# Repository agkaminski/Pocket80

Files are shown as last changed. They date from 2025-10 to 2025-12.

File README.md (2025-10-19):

# Pocket80

Personal computer with monitor software that fits into a pocket. Successor to the
[Pocket265](https://github.com/agkaminski/Pocket265) with more features and more
powerful Z80 CPU onboard.

Key features:
- Z80 CPU @3.6864 MHz,
- 32 KB of SRAM,
- 32 KB of EEPROM,
- Z80 CTC:
    - interval system timer,
    - baudrate generator,
    - sound (via onboard piezo driver).
- Z80 SIO:
    - USB UART port,
    - expansion connector UART port,
    - baudrate of up to 14400 baud/s.
- Z80 PIO:
    - onboard 64 KB of I2C EERPOM memory,
    - heartbeat LED,
    - expansion connector GPIOs.
- Build-in LiPo battery:
    - USB-C battery charging circuitry,
    - battery level indicator.

## Memory map

| Start  | End | Description |
|---|---|---|
| 0x0000 | 0x7FFF | ROM |
| 0x8000 | 0xFFFF | RAM |

## IO Map

| Start | End  | Description |
|---|---|---|
| 0x00  | 0x1F | Z80 CTC |
| 0x20  | 0x3F | Z80 SIO |
| 0x40  | 0x5F | Z80 PIO |
| 0x60  | 0x7F | Sound reset |
| 0x80  | 0x9F | Keyboard |
| 0xA0  | 0xBF | Display 1 (leftmost) |
| 0xC0  | 0xDF | Display 2 |
| 0xE0  | 0xFF | Display 3 |

## PCB visualisation

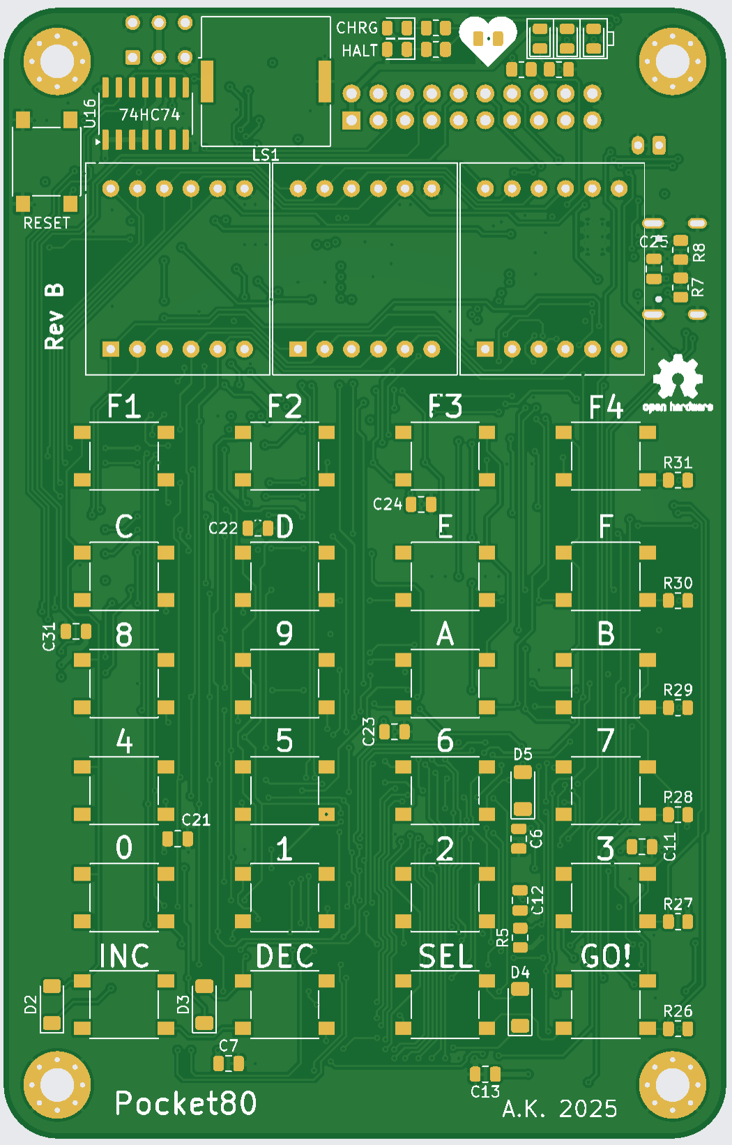
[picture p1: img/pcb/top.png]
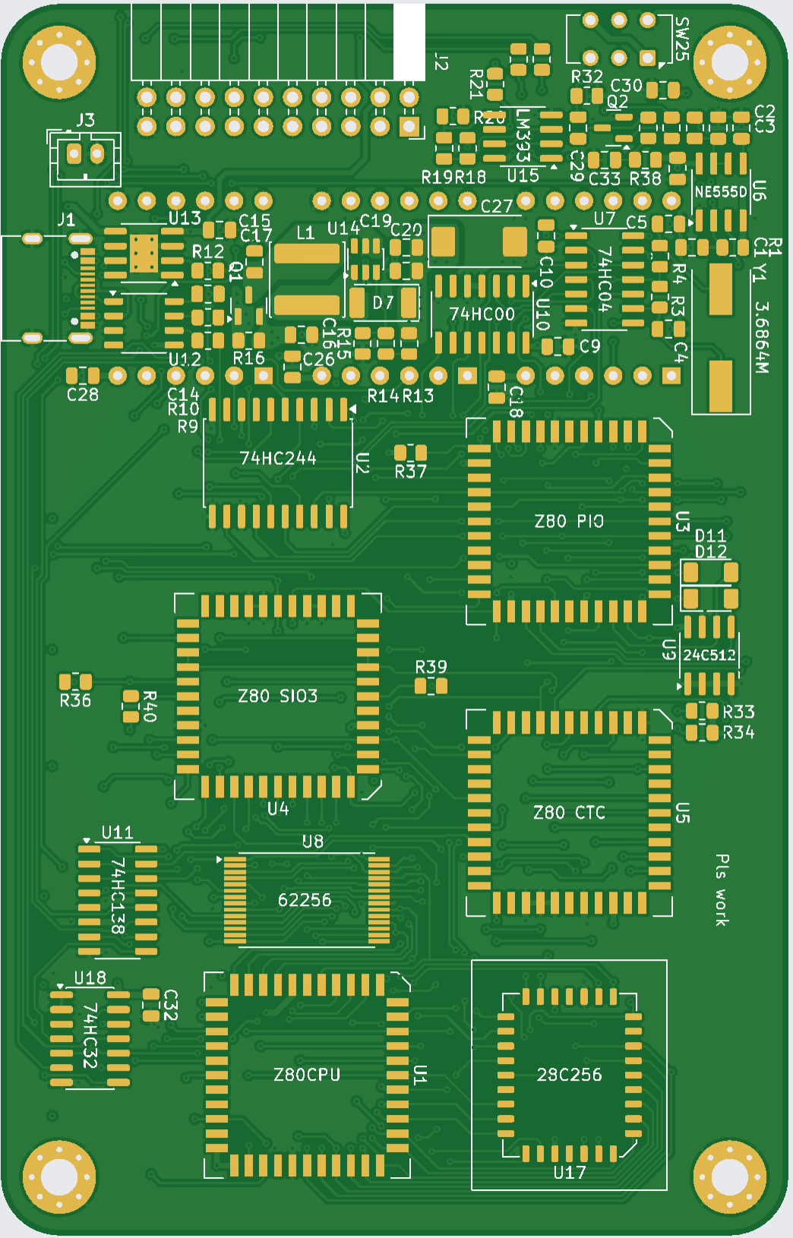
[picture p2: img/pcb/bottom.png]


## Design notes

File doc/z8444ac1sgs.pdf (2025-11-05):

Powered by ICminer.com Electronic-Library Service CopyRight 2003

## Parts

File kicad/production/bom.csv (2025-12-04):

Designator | Footprint | Quantity | Value | LCSC Part #
C1, C10, C11, C12, C13, C14, C17, C18, C19, C21, C22, C23, C24, C25, C26, C28, C30, C31, C32, C6, C7, C8, C9 | 0805 | 23 | 100n
C15, C16, C20 | 0805 | 3 | 22u
C2 | 0805 | 1 | 10n
C27 | CP_EIA-7343-15_Kemet-W | 1 | 68u
C29 | 0805 | 1 | 1u
C3 | 0805 | 1 | 220n
C33 | 0805 | 1 | 2u2
C4, C5 | 0805 | 2 | 22p
D1 | 0805 | 1 | HALT
D10 | 0805 | 1 | MEDIUM
D11, D12, D2, D3, D4, D5 | D_MiniMELF | 6 | 1N4148
D13 | 0805 | 1 | HEARTBEAT
D6 | 0805 | 1 | CHRG
D7 | 2010 | 1 | SS34
D8 | 0805 | 1 | POWER
D9 | 0805 | 1 | HIGH
DL1, DL2, DL3 | DL1414 | 3 | ~
J1 | USB_C_Receptacle_G-Switch_GT-USB-7010ASV | 1 | USB_C_Receptacle_USB2.0_14P
J2 | PinSocket_2x10_P2.54mm_Horizontal | 1 | Conn_02x10_Odd_Even
J3 | JST_PH_B2B-PH-K_1x02_P2.00mm_Vertical | 1 | Conn_01x02
L1 | L_Sunlord_SWPA6040S | 1 | 220u
LS1 | Buzzer_Murata_PKLCS1212E | 1 | Speaker_Crystal
Q1 | SOT-23 | 1 | IRLML6402
Q2 | SOT-23 | 1 | BC847
R1, R25, R26, R27, R28, R29, R30, R31, R32, R36, R37, R39, R40, R5 | 0805 | 14 | 10K
R10, R9 | 0805 | 2 | 220R
R11, R15, R17, R24, R4, R6 | 0805 | 6 | 1K
R12 | 0805 | 1 | 2K7
R13, R22, R35 | 0805 | 3 | 470R
R14 | 0805 | 1 | 6K8
R16, R2, R3 | 0805 | 3 | 1M
R18 | 0805 | 1 | 68K
R19 | 0805 | 1 | 47K
R20 | 0805 | 1 | 220K
R21 | 0805 | 1 | 100K
R23 | 0805 | 1 | 680R
R33, R34 | 0805 | 2 | 4K7
R38 | 0805 | 1 | 510R
R7, R8 | 0805 | 2 | 5K1
SW1 | SW_SPST_PTS645 | 1 | F1
SW10 | SW_SPST_PTS645 | 1 | 4
SW11 | SW_SPST_PTS645 | 1 | 9
SW12 | SW_SPST_PTS645 | 1 | 5
SW13 | SW_SPST_PTS645 | 1 | A
SW14 | SW_SPST_PTS645 | 1 | 6
SW15 | SW_SPST_PTS645 | 1 | B
SW16 | SW_SPST_PTS645 | 1 | 7
SW17 | SW_SPST_PTS645 | 1 | 0
SW18 | SW_SPST_PTS645 | 1 | INC
SW19 | SW_SPST_PTS645 | 1 | 1
SW2 | SW_SPST_PTS645 | 1 | F2
SW20 | SW_SPST_PTS645 | 1 | DEC
SW21 | SW_SPST_PTS645 | 1 | 2
SW22 | SW_SPST_PTS645 | 1 | SEL
SW23 | SW_SPST_PTS645 | 1 | 3
SW24 | SW_SPST_PTS645 | 1 | GO!
SW25 | SW_CK_JS202011AQN_DPDT_Angled | 1 | SW_Push_DPDT
SW26 | SW_SPST_PTS645 | 1 | RESET
SW3 | SW_SPST_PTS645 | 1 | F3
SW4 | SW_SPST_PTS645 | 1 | F4
SW5 | SW_SPST_PTS645 | 1 | C
SW6 | SW_SPST_PTS645 | 1 | D
SW7 | SW_SPST_PTS645 | 1 | E
SW8 | SW_SPST_PTS645 | 1 | F
SW9 | SW_SPST_PTS645 | 1 | 8
U1 | PLCC-44 | 1 | Z80CPU
U10 | SO-14_3.9x8.65mm_P1.27mm | 1 | 74HC00
U11 | SOIC-16_3.9x9.9mm_P1.27mm | 1 | 74HC138
U12 | SOP-8_3.9x4.9mm_P1.27mm | 1 | CH340N
U13 | SOIC-8-1EP_3.9x4.9mm_P1.27mm_EP2.41x3.3mm_ThermalVias | 1 | TP4056-42-ESOP8
U14 | TSOT-23-6 | 1 | SX1308
U15 | SOIC-8_3.9x4.9mm_P1.27mm | 1 | LM393
U16 | SO-14_3.9x8.65mm_P1.27mm | 1 | 74HC74
U17 | PLCC-32_11.4x14.0mm_P1.27mm | 1 | 28C256
U18 | SO-14_3.9x8.65mm_P1.27mm | 1 | 74HC32
U2 | SOIC-20W_7.5x12.8mm_P1.27mm | 1 | 74HC244
U3 | PLCC-44 | 1 | Z80 PIO
U4 | PLCC-44 | 1 | Z80 SIO3
U5 | PLCC-44 | 1 | Z80 CTC
U6 | SOIC-8_3.9x4.9mm_P1.27mm | 1 | NE555D
U7 | SO-14_3.9x8.65mm_P1.27mm | 1 | 74HC04
U8 | TSOP-I-28_11.8x8mm_P0.55mm | 1 | 62256
U9 | SOIC-8_3.9x4.9mm_P1.27mm | 1 | 24C512
Y1 | Crystal_SMD_HC49-SD | 1 | 3.6864M

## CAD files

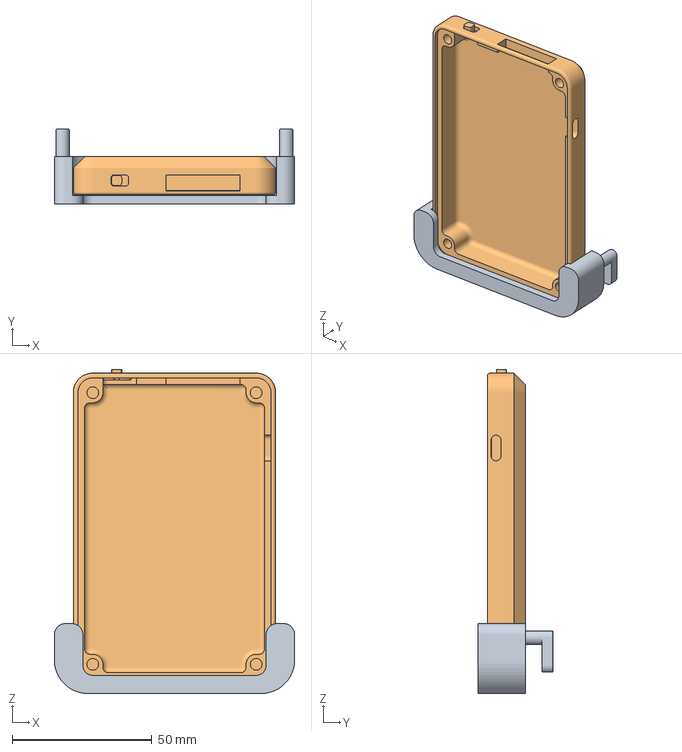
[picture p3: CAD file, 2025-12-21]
3d/skadis_hanger.FCStd
86.0 x 27.0 x 115.9 mm
hanger
caseB

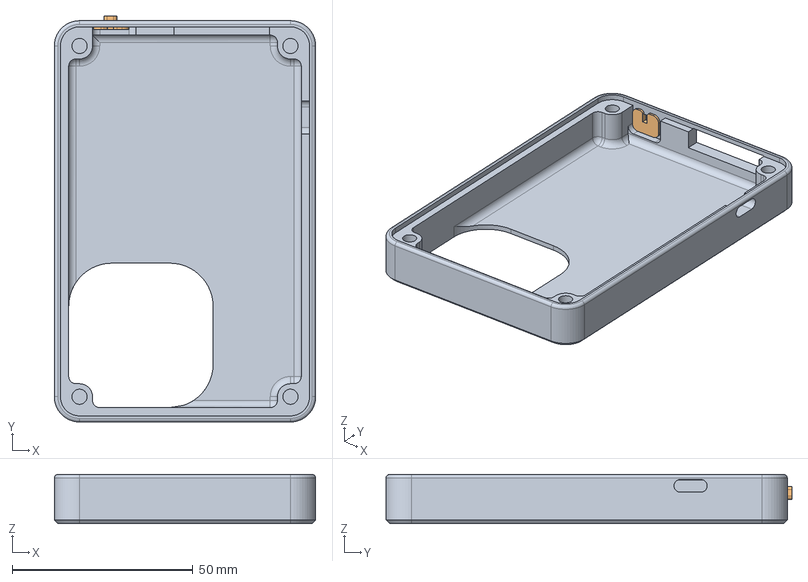
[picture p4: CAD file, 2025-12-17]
3d/caseB_dev.FCStd
72.4 x 112.5 x 13.6 mm
Case
Switch

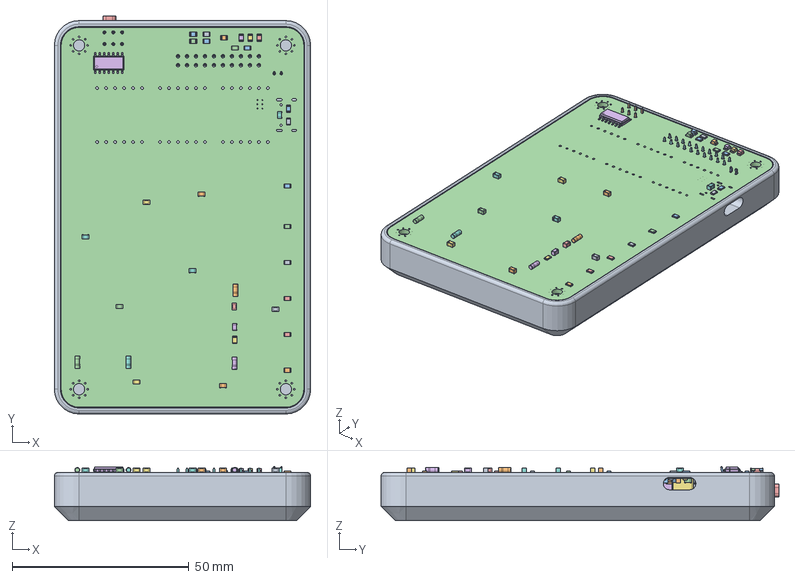
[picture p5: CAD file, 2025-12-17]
3d/caseB.FCStd
72.4 x 112.5 x 15.3 mm
Case
LED_0805_2012Metric
R_0805_2012Metric
LED_0805_2012Metric001
R_0805_2012Metric001
C_0805_2012Metric
LED_0805_2012Metric002
C_0805_2012Metric001
C_0805_2012Metric002
C_0805_2012Metric003
R_0805_2012Metric002
D_MiniMELF
C_0805_2012Metric004
SO-14_3.9x8.65mm_P1.27mm
C_0805_2012Metric005
C_0805_2012Metric006
R_0805_2012Metric003
D_MiniMELF001
R_0805_2012Metric004
R_0805_2012Metric005
R_0805_2012Metric006
D_MiniMELF002
R_0805_2012Metric007
C_0805_2012Metric007
R_0805_2012Metric008
C_0805_2012Metric008
R_0805_2012Metric009
C_0805_2012Metric009
LED_0805_2012Metric003
LED_0805_2012Metric004
C_0805_2012Metric010
D_MiniMELF003
R_0805_2012Metric010
R_0805_2012Metric011
LED_0805_2012Metric005
R_0805_2012Metric012
R_0805_2012Metric013
R_0805_2012Metric014
C_0805_2012Metric011
SOT-23
R_0805_2012Metric015
R_0805_2012Metric016
C_0805_2012Metric012
SOIC-8_3.9x4.9mm_P1.27mm
SOT-024
SO-14_3.9x8.65mm_P1.27mm001
R_0805_2012Metric017
TSOP-I-28_11.8x8mm_P0.55mm
C_0805_2012Metric013
R_0805_2012Metric018
C_0805_2012Metric014
R_0805_2012Metric019
SOIC-20W_7.5x12.8mm_P1.27mm
SOIC-8_3.9x4.9mm_P1.27mm001
R_0805_2012Metric020
C_0805_2012Metric015
R_0805_2012Metric021
D_MiniMELF004
C_0805_2012Metric016
SOIC-8_3.9x4.9mm_P1.27mm002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

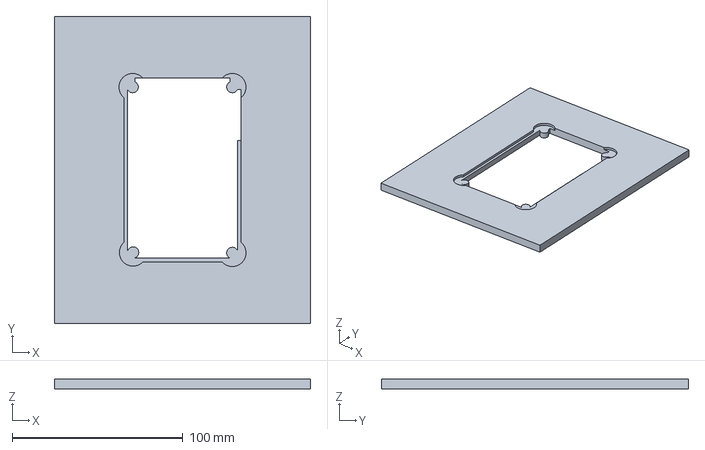
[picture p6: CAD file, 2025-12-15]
3d/solder_jig.FCStd
150.0 x 180.0 x 6.00 mm

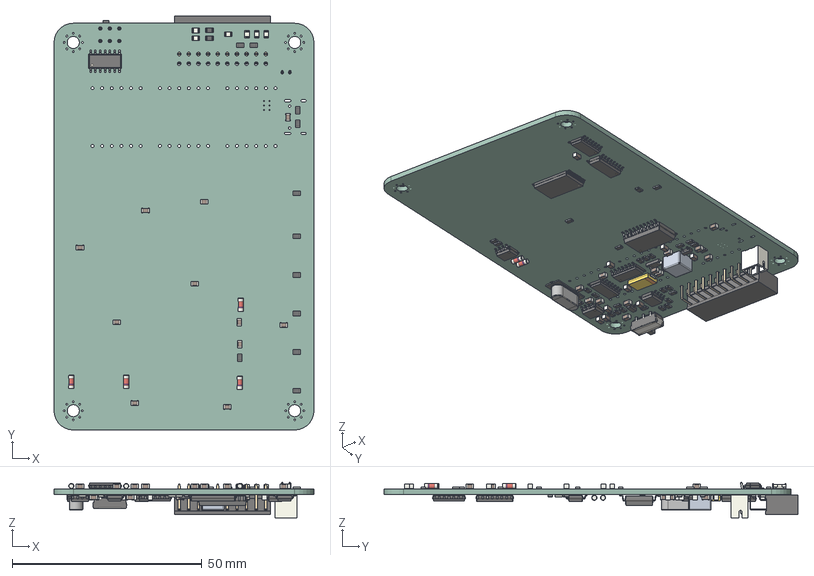
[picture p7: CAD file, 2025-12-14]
3d/pocket80.step
68.6 x 109.2 x 9.40 mm
LED_0805_2012Metric x 6
R_0805_2012Metric x 40
C_0805_2012Metric x 32
D_MiniMELF x 6
SO-14_3.9x8.65mm_P1.27mm x 4
SOT-23 x 2
SOIC-8_3.9x4.9mm_P1.27mm x 3
TSOP-I-28_11.8x8mm_P0.55mm
SOIC-20W_7.5x12.8mm_P1.27mm
SW_CK_JS202011AQN_DPDT_Angled
Crystal_SMD_HC49-SD
PinSocket_2x10_P2.54mm_Horizontal
CP_EIA-7343-15_Kemet-W
TSOT-23-6
JST_PH_B2B-PH-K_1x02_P2.00mm_Vertical
SOIC-16_3.9x9.9mm_P1.27mm
D_2010_5025Metric
pocket80_PCB

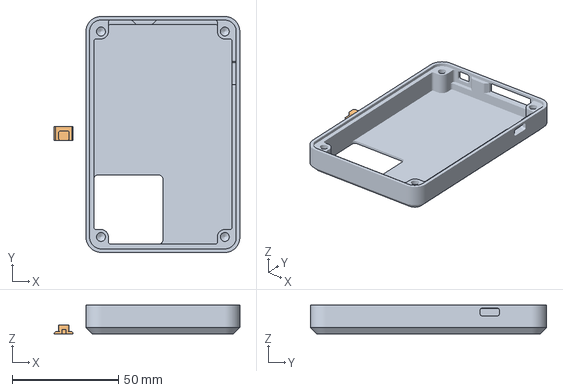
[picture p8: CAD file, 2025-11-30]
3d/case_debug.3mf
87.6 x 111.3 x 13.6 mm
case_debug_1
case_debug_2

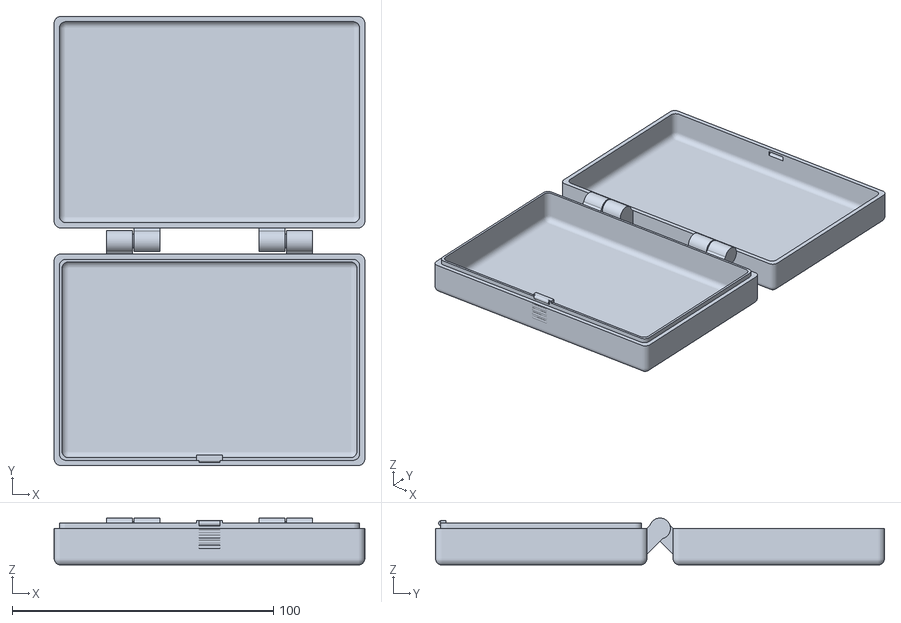
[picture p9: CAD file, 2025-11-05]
3d/box.stl
119.0 x 172.0 x 18.0

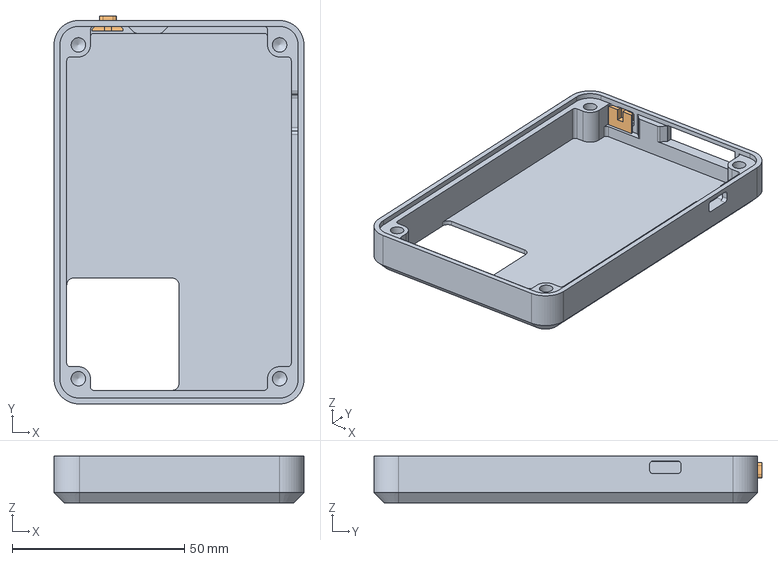
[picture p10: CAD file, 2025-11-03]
3d/case.FCStd
72.6 x 112.6 x 13.6 mm
Case
Switch

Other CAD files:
3d/case.3mf
3d/caseB.3mf
3d/caseB_dev.3mf
3d/skadis_hanger.3mf
3d/solder_jig.3mf

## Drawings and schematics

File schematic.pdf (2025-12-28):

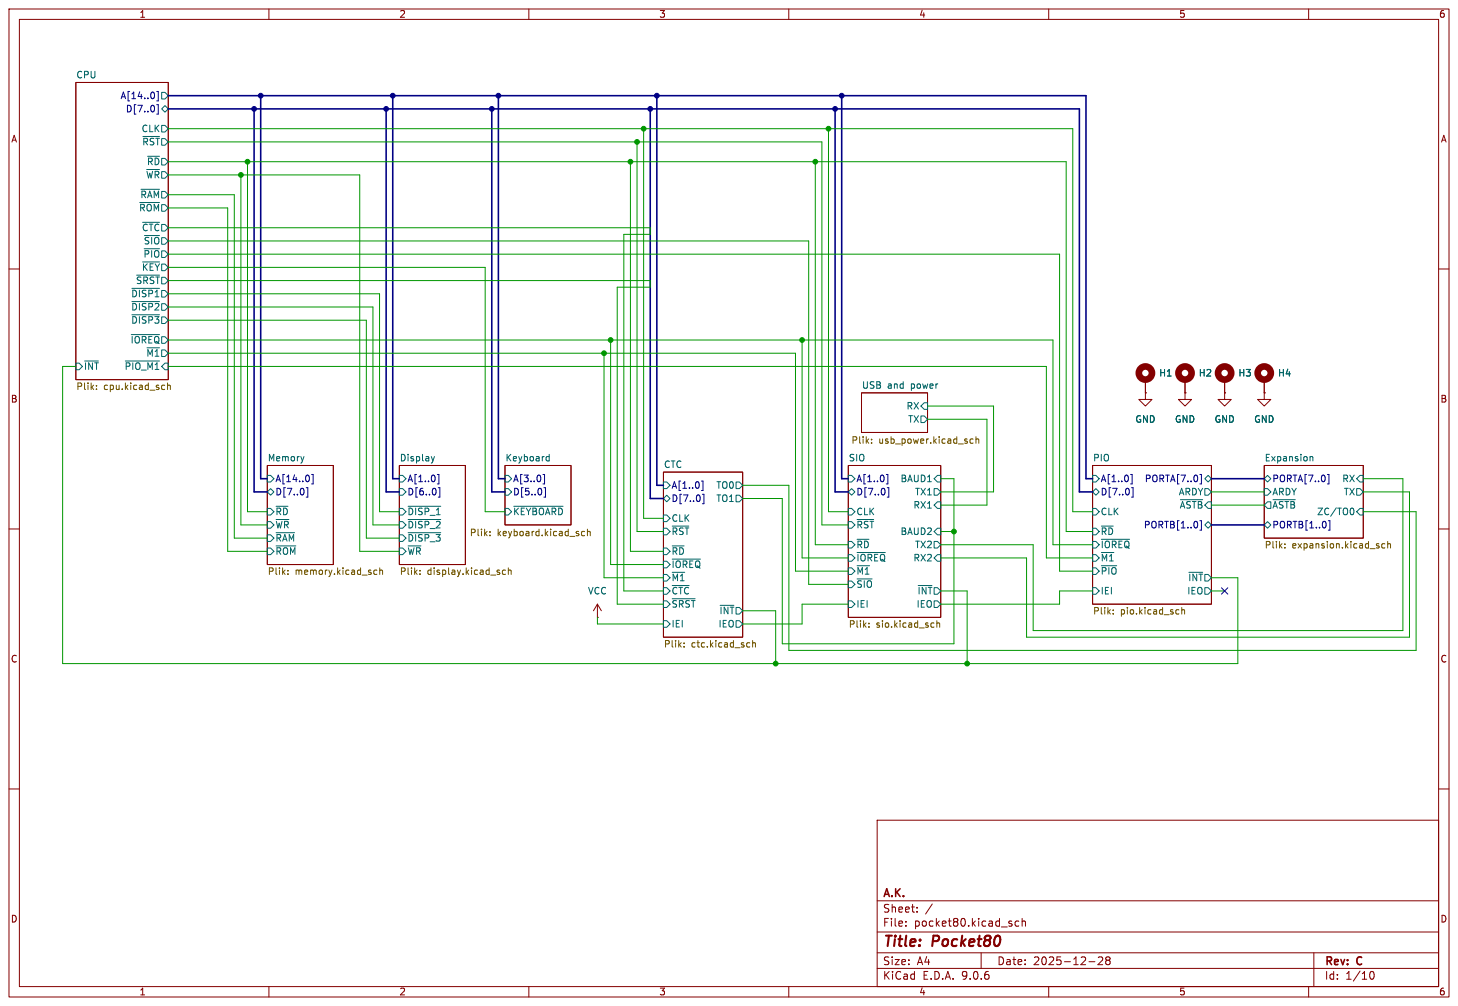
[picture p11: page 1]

TX USB and power Plik: usb_power.kicad_sch

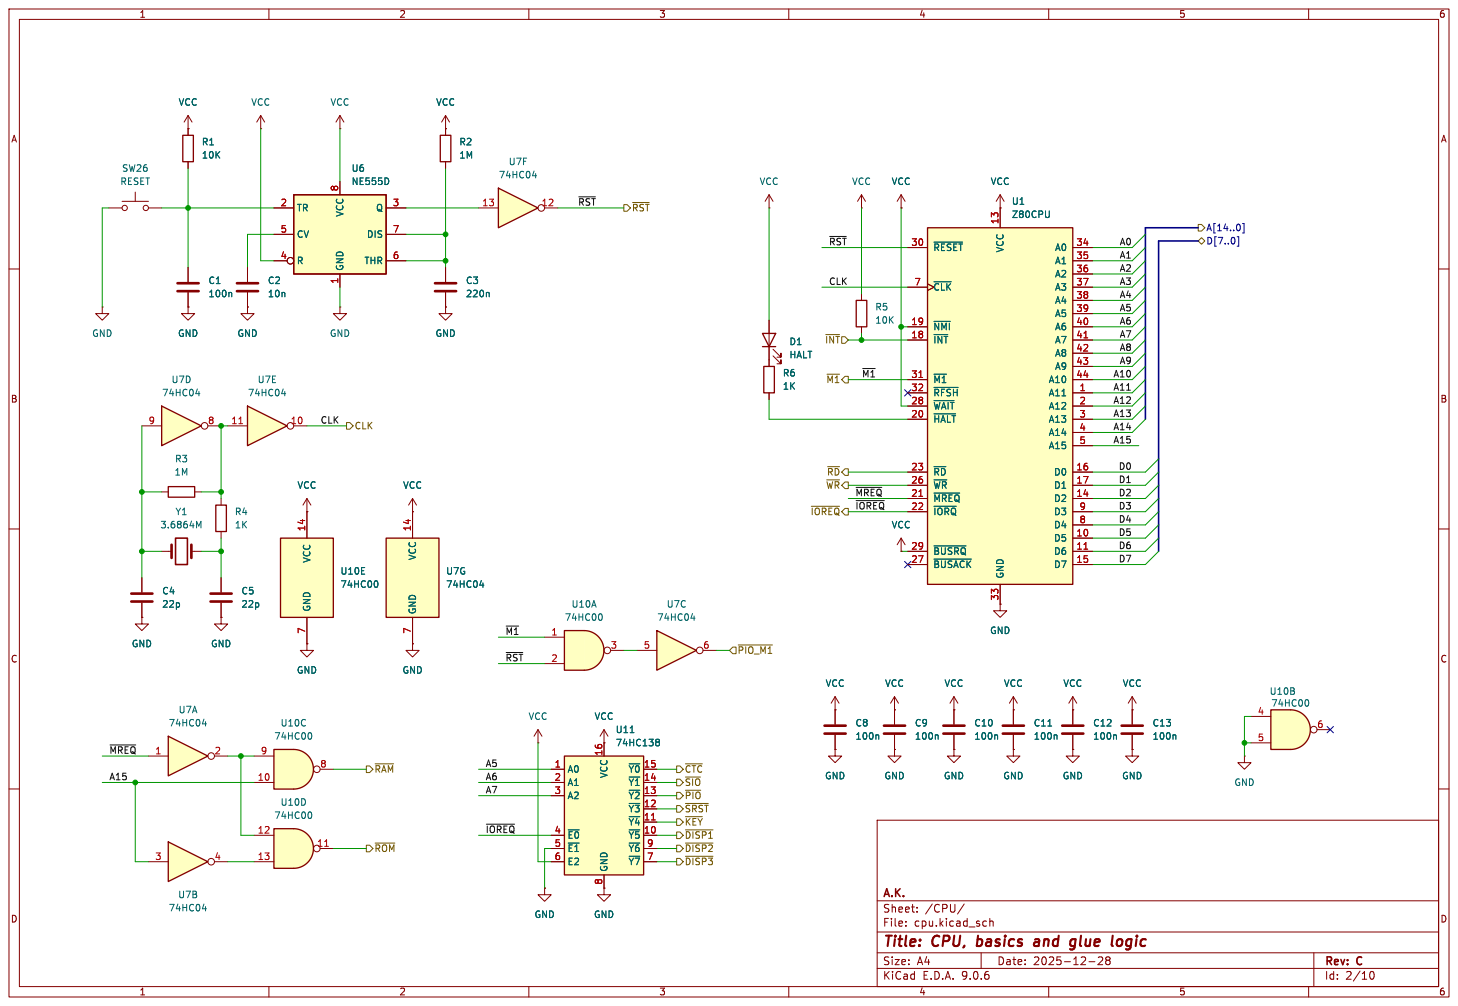
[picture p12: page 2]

8 ~{Y0}15 ~{Y1}14 ~{Y2}13 ~{Y3}12 ~{Y4}11 ~{Y5}10 ~{Y6}9 ~{Y7}7 GND GND GND GND

Id: 2/10 Title: CPU, basics and glue logic

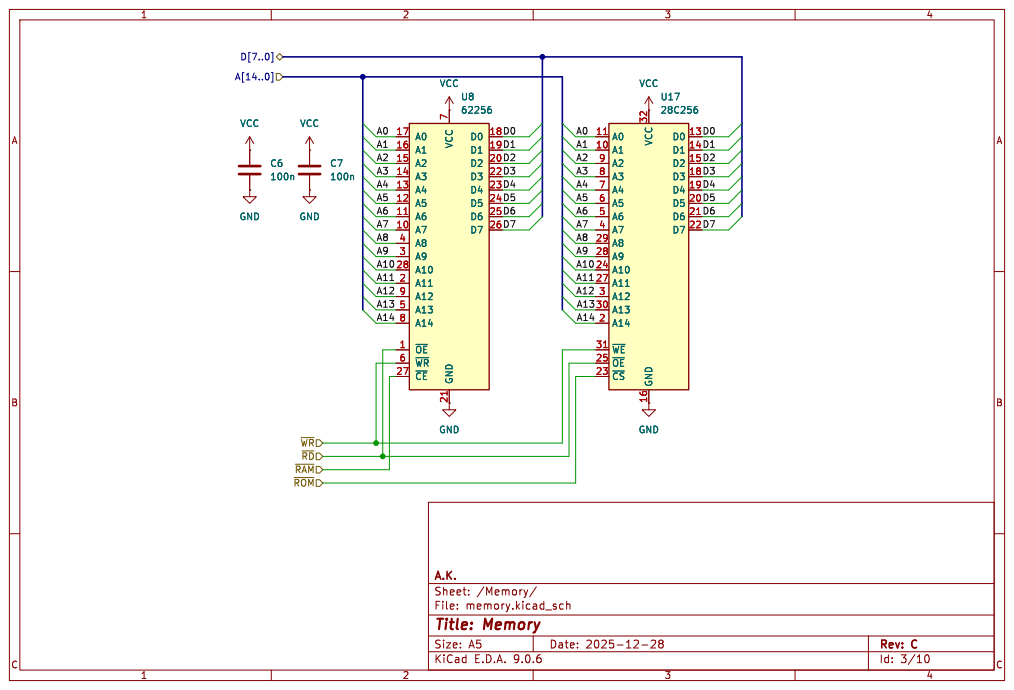
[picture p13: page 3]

File: memory.kicad_sch Sheet: /Memory/ A.K. GND

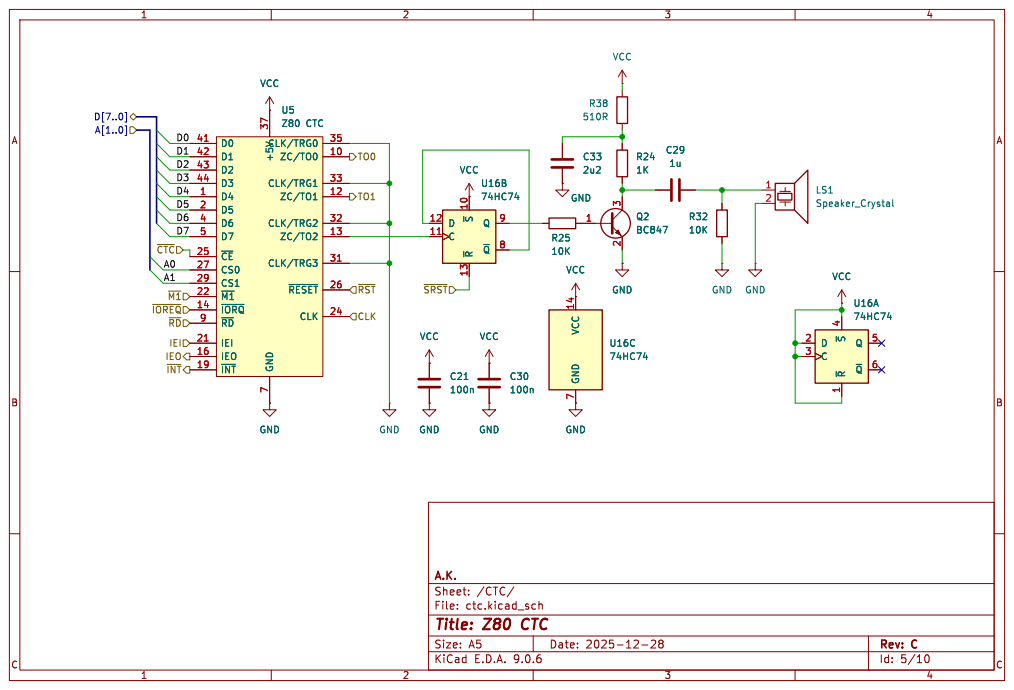
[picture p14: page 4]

7 CLK/TRG0 35 ZC/TO0 10 CLK/TRG1 33 ZC/TO1 12 CLK/TRG2 32 ZC/TO2 13 CLK/TRG3 31 ~{RESET}26 CLK 24 VCC GND

7 CLK/TRG0 35 ZC/TO0 10 CLK/TRG1 33 ZC/TO1 12 CLK/TRG2 32 ZC/TO2 13 CLK/TRG3 31 ~{RESET}26 CLK 24 U5 Z80 CTC

VCC VCC GNDVCC 14 GND

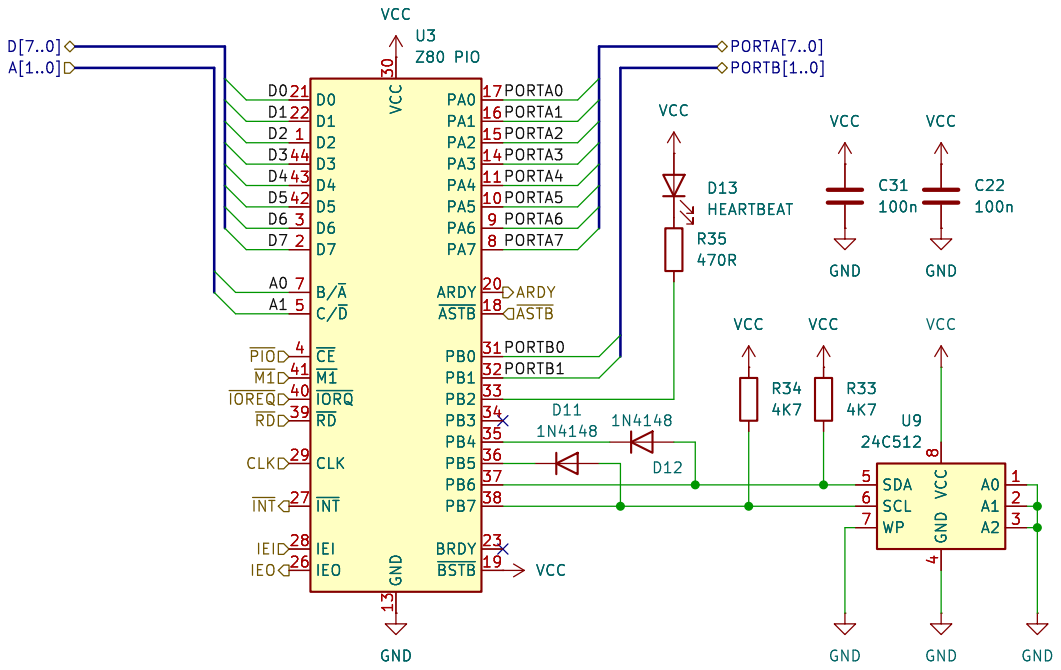
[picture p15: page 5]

File: pio.kicad_sch Sheet: /PIO/ A.K. R34
24C512 GND

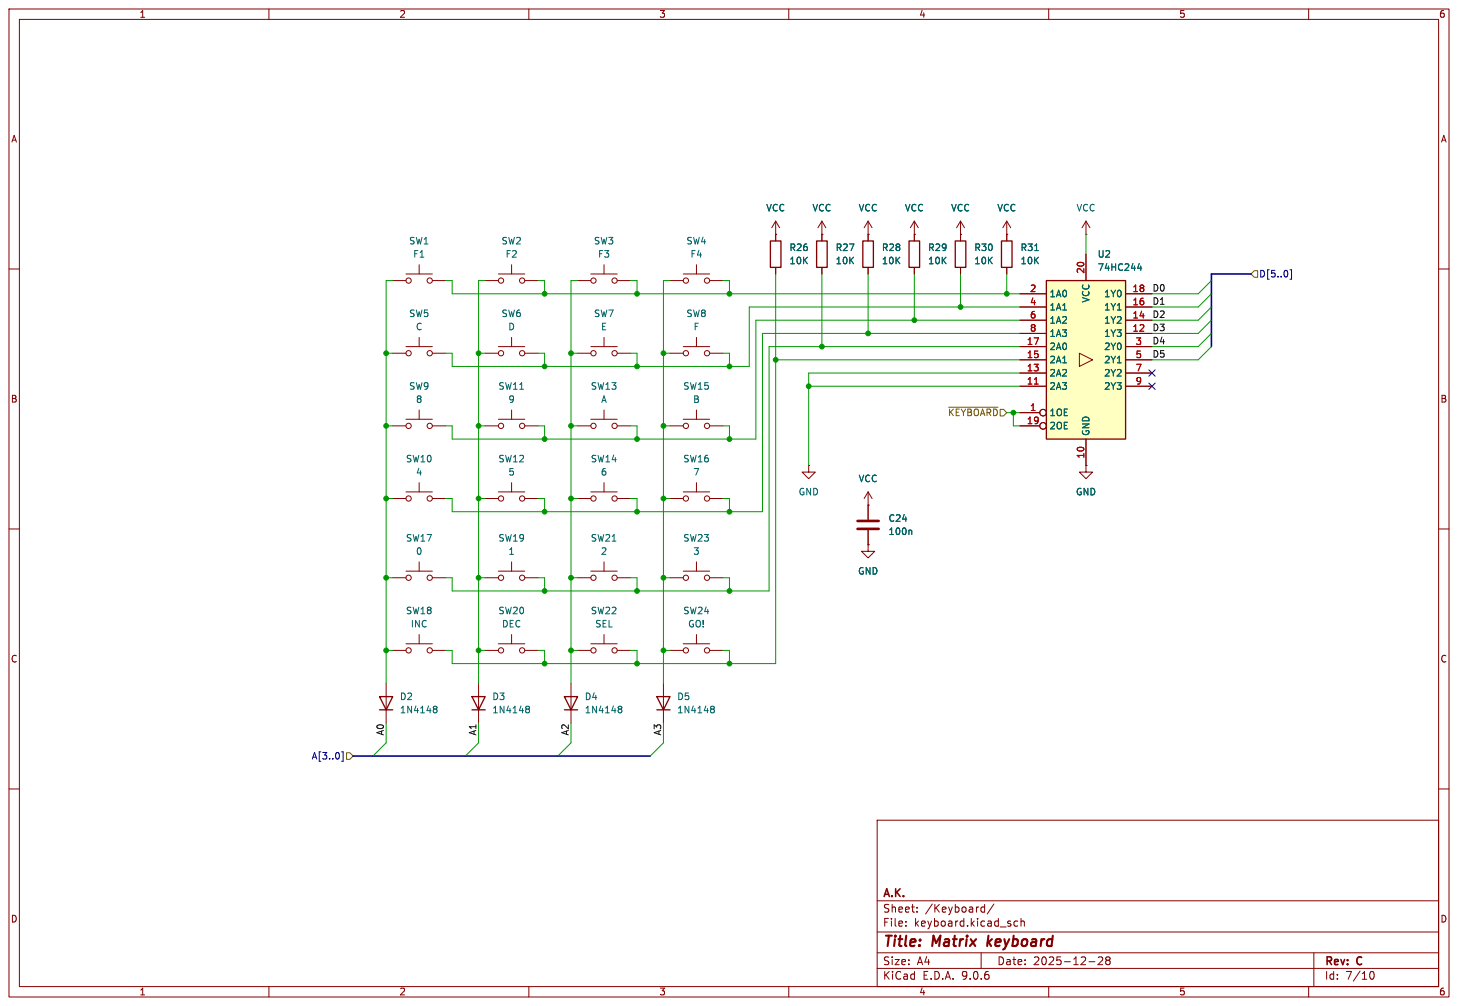
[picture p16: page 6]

File: keyboard.kicad_sch Sheet: /Keyboard/ A.K. SW23

Id: 7/10 Title: Matrix keyboard

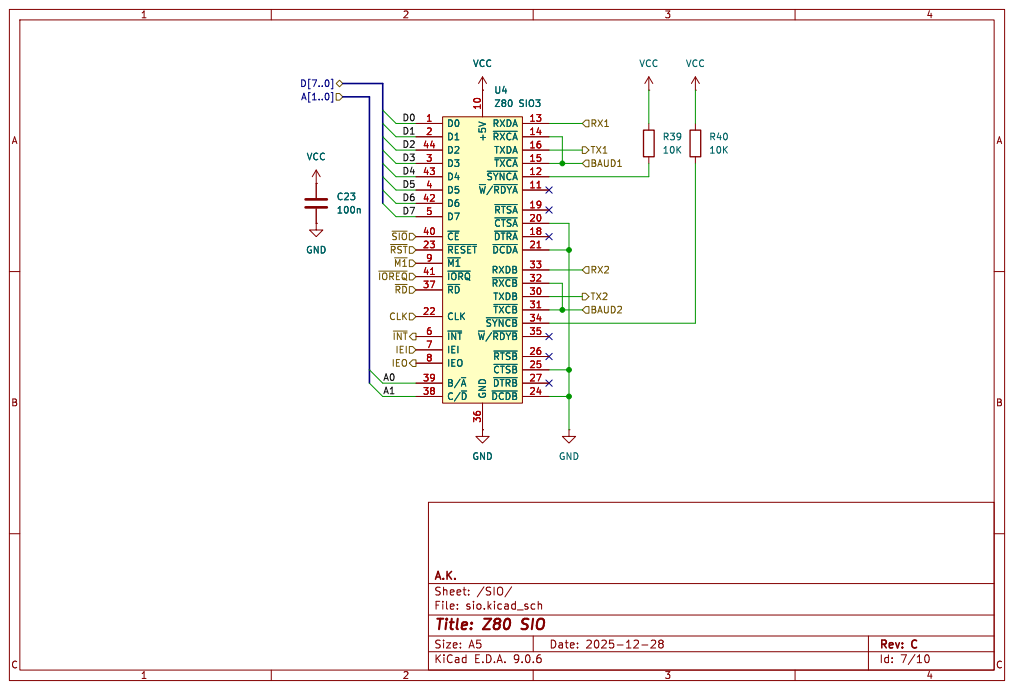
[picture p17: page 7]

File: sio.kicad_sch Sheet: /SIO/ A.K.

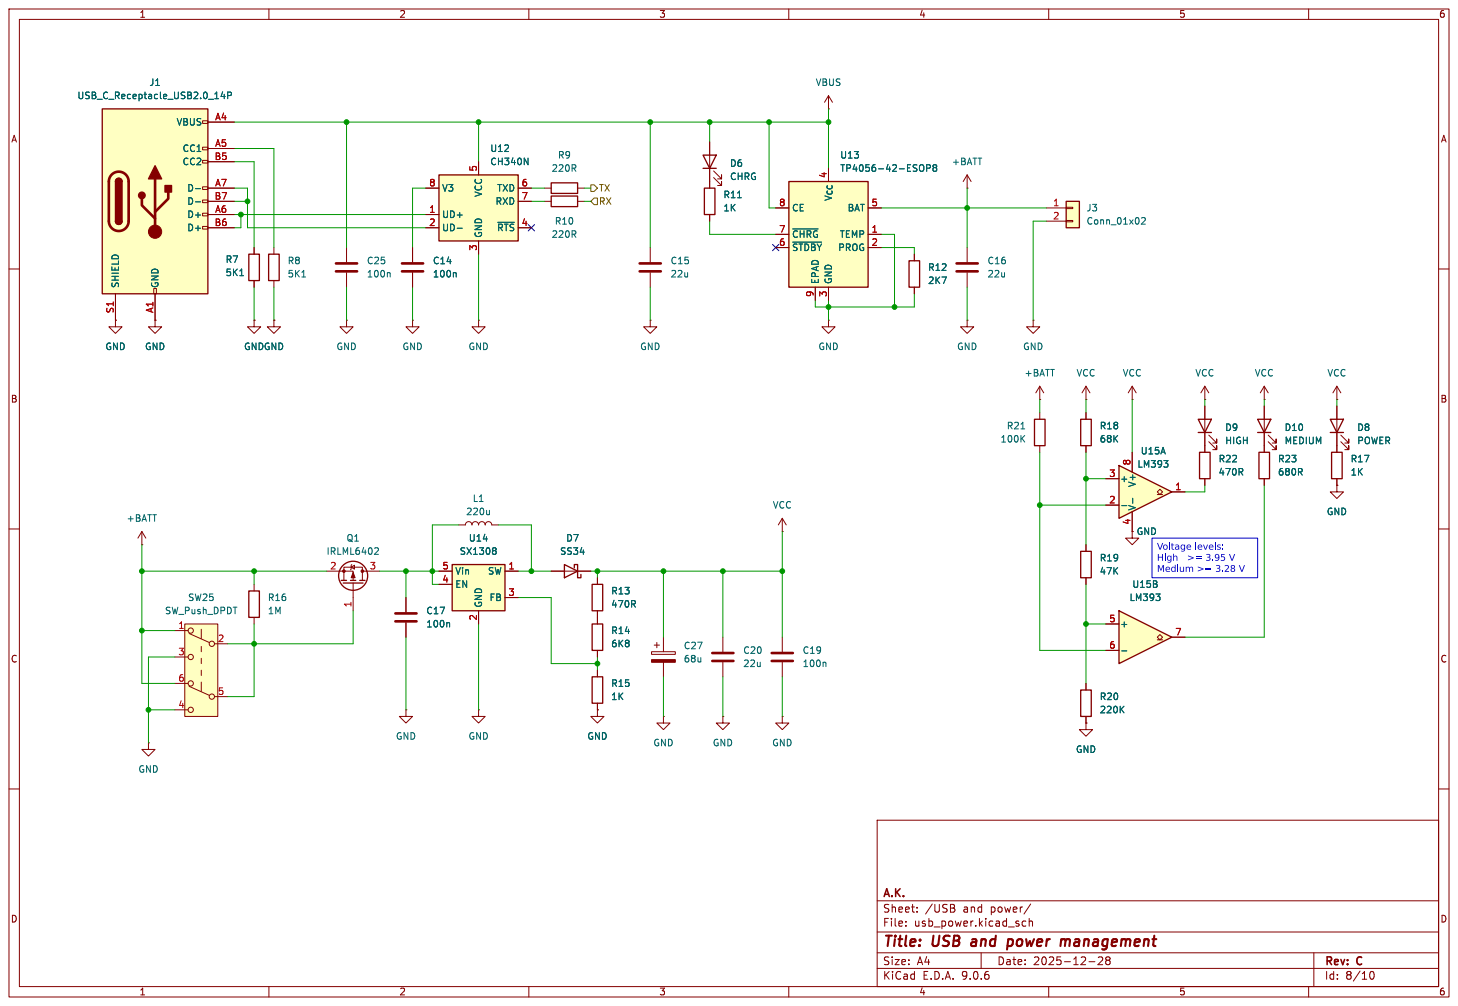
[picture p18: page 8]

3 TXD 6 RXD 7 ~{RTS}4 U12 CH340N GND GND GND GND

3 BAT 5 TEMP 1 PROG 2 U13 TP4056-42-ESOP8 VCC

Voltage levels: High >= 3.95 V Medium >= 3.28 V R12

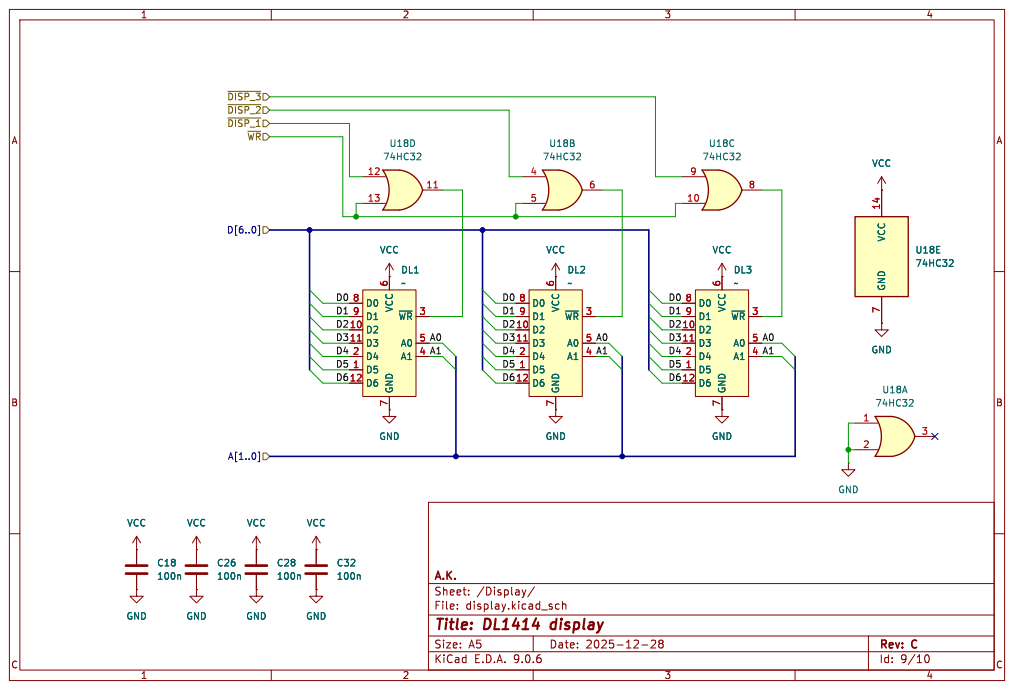
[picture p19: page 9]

7 ~{WR}3 A0 5 A1 4 DL3 ~ VCC GND GND GND

7 ~{WR}3 A0 5 A1 4 VCC VCC GND GND

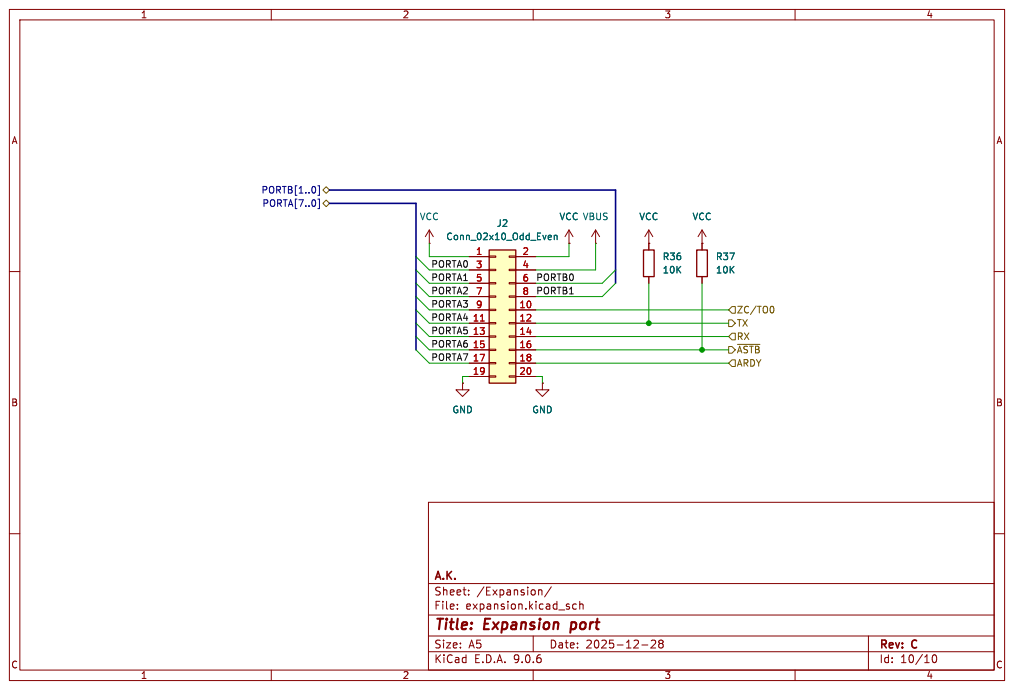
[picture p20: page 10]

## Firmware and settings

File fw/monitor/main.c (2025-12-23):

/* Pocket80 monitor main
 * A.K. 2025
 */

#include <string.h>

#include "driver/dl1414.h"
#include "driver/ctc.h"
#include "driver/sio.h"

static void beep(void)
{
	ctc_control(2, CTC_PRESCALE_16 | CTC_RELOAD | CTC_CONTROL | ((144 / 2) << 8));
	for (volatile int i = 0; i < 1000; ++i);
	ctc_control(2, CTC_RESET | CTC_CONTROL);
}

int main(void)
{
	memcpy(dl1414_buff, "[ POCKET80 ]", 12);
	dl1414_update();

	/* Buzzer test */
	beep();

	/* Baud generator */
	ctc_control(1, CTC_PRESCALE_16 | CTC_RELOAD | CTC_CONTROL | (1 << 8));

	sio_init();

	for (size_t i = 0; i < 12; ++i) {
		sio_write(0, dl1414_buff[i]);
	}

	sio_write(0, '\r');
	sio_write(0, '\n');

	for (;;) {
		uint8_t data = sio_read(0);
		sio_write(0, data);

		beep();

		memmove(dl1414_buff + 1, dl1414_buff, 11);
		dl1414_buff[0] = data;
		dl1414_update();
	}

	return 0;
}

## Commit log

2025-10-13 HW: CPU and memory schematic
    [cpu.kicad_sch, memory.kicad_sch, pocket80.kicad_pcb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]
2025-10-14 HW: Initial placement of I/O chips
    [cpu.kicad_sch, ctc.kicad_sch, io.kicad_sch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]
2025-10-14 HW: Add keyboard
    [keyboard.kicad_sch, pocket80.kicad_sch]
2025-10-14 HW: Add USB-C and battery charger
    [pocket80.kicad_sch, usb_power.kicad_sch]
2025-10-14 HW: Update schematic info frames
    [cpu.kicad_sch, ctc.kicad_sch, keyboard.kicad_sch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]
2025-10-14 HW: Add DC-DC step-up converter
    [usb_power.kicad_sch]
2025-10-14 HW: Add power switch
    [usb_power.kicad_sch]
2025-10-14 HW: Add battery state indicator
    [usb_power.kicad_sch]
2025-10-16 HW: Add display, start PCB placement
    [cpu.kicad_sch, ctc.kicad_sch, display.kicad_sch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]
2025-10-16 HW: Finish CTC sound generator
    [ctc.kicad_sch, pocket80.kicad_pcb, pocket80.kicad_sch]
2025-10-16 HW: Replace 28C64/27C64 EEPROM with 28C256
    [memory.kicad_sch, pocket80.kicad_pcb]
2025-10-16 HW: Add rst button, sync pins
    [cpu.kicad_sch, pocket80.kicad_pcb, pocket80.kicad_sch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]
2025-10-16 HW: PIO done
    [cpu.kicad_sch, ctc.kicad_sch, display.kicad_sch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]
2025-10-16 HW: Start final placement
    [expansion.kicad_sch, keyboard.kicad_sch, pio.kicad_sch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]
2025-10-17 HW: Fix mounting holes
    [pocket80.kicad_pcb, pocket80.kicad_sch]
2025-10-17 HW: placement finished
    [keyboard.kicad_sch, pocket80.kicad_pcb]
2025-10-17 HW: Add LiPo connector
    [pocket80.kicad_pcb, usb_power.kicad_sch]
2025-10-17 HW: Initial power routing
    [pocket80.kicad_pcb]
2025-10-18 HW: Routing WIP
    [pocket80.kicad_pcb]
2025-10-18 HW: Routing done
    [pocket80.kicad_pcb]
2025-10-18 HW: Rev A
    [bom.csv, cpu.kicad_sch, ctc.kicad_sch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]
2025-10-19 Repositor cleanup, add README
    [bom.csv, cpu.kicad_sch, ctc.kicad_sch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]
2025-10-19 Add PCB images
2025-10-19 HW: Replace .step file
    [pocket80.kicad_pcb]
2025-10-19 HW: Fix slight mounting hole offset
    [pocket80.kicad_pcb]
2025-10-19 3d: Add case
    [case.3mf, case.FCStd]
2025-10-19 HW: Add pull-ups to the expansion slot inputs
    [expansion.kicad_sch, pocket80.kicad_pcb]
2025-10-19 3d: Fix case too small thickness
    [case.3mf, case.FCStd]
2025-10-19 3d: Add rev A PCB 3d model
    [pcb.3mf]
2025-10-19 3d: Add solder paste jig
    [solder_jig.3mf, solder_jig.FCStd]
2025-10-20 3d: Update case
    [case.3mf, case.FCStd]
2025-10-20 3d: Update solder jig
    [solder_jig.3mf, solder_jig.FCStd]
2025-11-01 HW: Fix SX1308 footprint TSOT23-5 -> TSOT23-6
    [pocket80.kicad_pcb, usb_power.kicad_sch]
2025-11-01 3d: update soldering jig
    [solder_jig.3mf, solder_jig.FCStd]
2025-11-03 HW: Fix lack of /WR gating for DL1414
    [bom.csv, cpu.kicad_sch, ctc.kicad_sch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]
2025-11-05 3d: Add box
    [box.stl]
2025-11-05 FW: Add CTC driver
2025-11-13 HW: Mechanical improvement
    - move USB invards to clear the case,
    - extend expansion connector to be flush with the case.
    [pocket80.kicad_pcb, positions.csv]
2025-11-30 FW: Add DL1414 driver
2025-11-30 3D: Add debug case (EEPROM access window)
    [case_debug.3mf]
2025-11-30 FW: working piezo buzzer and Z80 CTC
    [main.c]
2025-12-01 HW: add piezo power filter
    [bom.csv, cpu.kicad_sch, ctc.kicad_sch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]
2025-12-04 HW: fix floating SYNC pins of SIO
    [bom.csv, cpu.kicad_sch, ctc.kicad_sch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]
2025-12-05 FW: fix Makefile
    - allow prefixed sdcc tools
    - fix drivers dir not being cleaned
2025-12-14 3D: Update .step to rev B
    [pcb.3mf, pocket80.step]
2025-12-14 3D: Add rev B case model
    [caseB.3mf, caseB.FCStd, caseB_dev.3mf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]
2025-12-14 3D: Increase Z power switch clearance
    [caseB.3mf, caseB.FCStd, caseB_dev.3mf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]
2025-12-14 3D: Increase tolerances
    [caseB.3mf, caseB.FCStd, caseB_dev.3mf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]
2025-12-15 3D: Increase depth of soldering jig
    [solder_jig.3mf, solder_jig.FCStd]
2025-12-17 HW: Fix power switch pinout
    thx kicad for no coherent pin numeration convention
    and random shuffle on footprint assigment...
    [cpu.kicad_sch, ctc.kicad_sch, display.kicad_sch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]
2025-12-17 3D: Make power switch clearance bigger
    [caseB.3mf, caseB.FCStd, caseB_dev.3mf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]
2025-12-20 FW: Handle EI when interrupts not ready
2025-12-21 3D: Add Skadis pegboard hanger
    [skadis_hanger.3mf, skadis_hanger.FCStd]
2025-12-21 FW: Build drivers as a lib
2025-12-22 FW: Optimize CTC driver
2025-12-22 FW: Optimize SIO driver
2025-12-23 FW: Adapt monitor to changes in drivers
2025-12-28 HW: Fix initial IEI not being connected
    [cpu.kicad_sch, ctc.kicad_sch, display.kicad_sch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]
2026-11-09 FW: Initial SIO driver
2026-11-09 3D: Add case resin print .step model
